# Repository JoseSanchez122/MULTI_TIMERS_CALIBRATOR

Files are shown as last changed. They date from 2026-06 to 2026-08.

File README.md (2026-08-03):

# MULTI_TIMERS_CALIBRATOR

Hardware_design



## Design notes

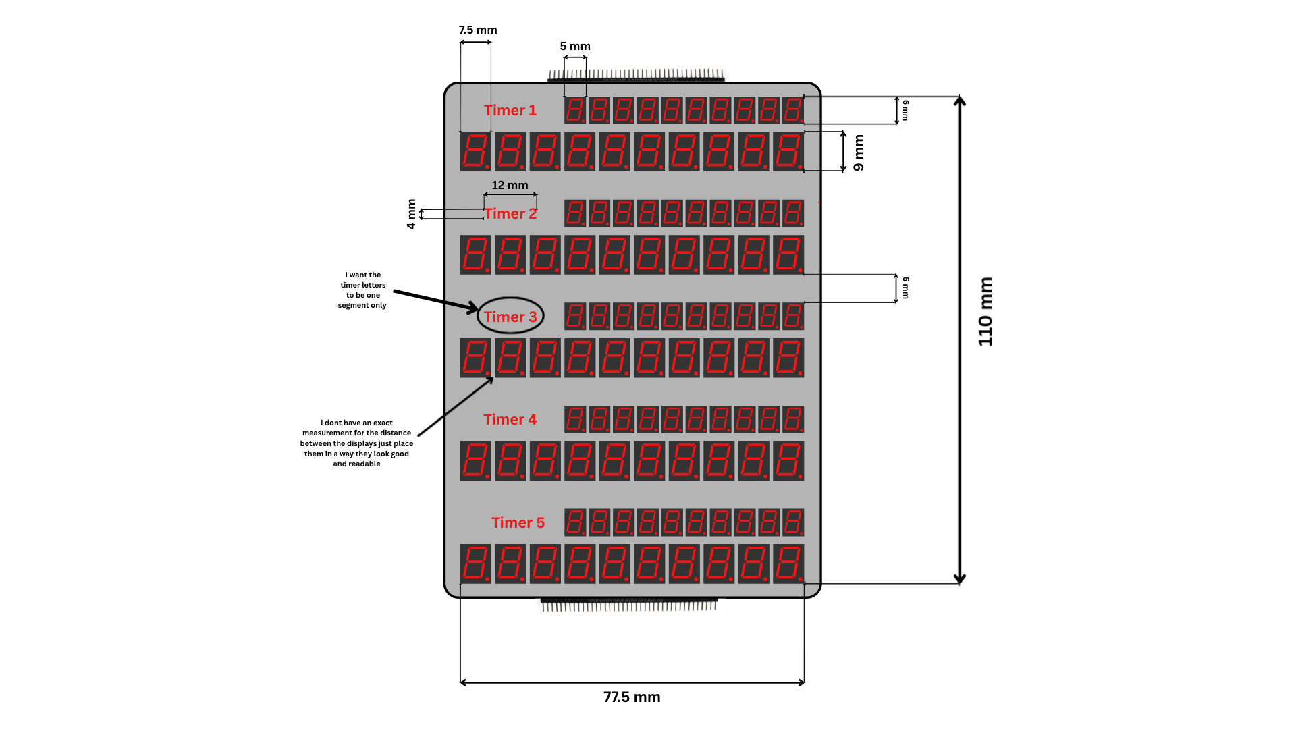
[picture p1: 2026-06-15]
Hardware_design/datasheets/Displays_datasheets/display.png

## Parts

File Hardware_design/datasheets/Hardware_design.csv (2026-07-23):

Id | Designator | Footprint | Quantity | Designation | Supplier and ref
1 | C1, C2, C3, C7 | 0805_SMD_CERAMIC_CAP_T491B106K016AT | 4 | 0.1uF
2 | C4, C8, C12, C13, C23, C24, C35, C36 | 0805_SMD_TANT_CAP_T491B106K016AT | 8 | 10uF
3 | C5, C6 | 0805_SMD_CERAMIC_CAP_T491B106K016AT | 2 | 15 pF
4 | C9, C10, C14, C15, C16, C17, C18, C19, C20, C21, C22, C25, C26, C27, C28, C29, C30, C31, C32, C33, C37 | 0805_SMD_CERAMIC_CAP_T491B106K016AT | 21 | 0.1 uF
5 | C11 | 0805_SMD_CERAMIC_CAP_T491B106K016AT | 1 | 1 uF
6 | D1 | Schottky_diode_BAT54S | 1 | BAT54S
7 | D2 | GREEN_LED_LTST-C170KGKT | 1 | LTST-C170KGKT
8 | D3, D4, D5, D6, D7, D8, D9, D10 | DIO_Schottky _MBR0530T3G | 8 | D_Schottky
9 | DS1, DS2, DS3, DS4, DS5, DS6, DS7, DS8, DS9, DS10, DS11, DS12, DS13, DS14, DS15, DS16, DS17, DS18, DS19, DS20, DS21, DS22, DS23, DS24, DS25, DS26, DS27, DS28, DS29, DS30, DS31, DS32, DS33, DS34, DS35, DS36, DS45, DS46, DS47, DS48, DS49, DS50, DS51, DS52, DS53, DS54, DS55, DS56, DS57, DS58, DS59, DS60, DS61, DS62, DS63, DS64, DS65, DS66, DS67, DS68, DS69, DS70, DS71, DS72, DS73, DS74, DS75, DS76 | SMD_DISPLAY_ACSC03-41EWA-F01 | 68 | ACSC03-41EWA-F01
10 | E1 | VNC_CONECTOR_1-1337445-0 | 1 | 1-1337445-0
11 | IC1 | ESP32S3WROOM1N16 | 1 | ESP32-S3-WROOM-1-N16
12 | J1 | PROG_CONECTOR_SAMTEC_FTSH-103-01-F-D | 1 | FTSH-103-01-F-D
13 | J2 | 4_pin_FTR-104-01-L-S | 1 | Conn_01x04_Pin
14 | J3 | POWER_CONE_54-00131 | 1 | 54-00131
15 | LS1 | BUZZER_CMI-9605IC-0580T | 1 | CMI-9605IC-0580T
16 | Q1 | TRANSISTOR_MMBT2222A | 1 | MMBT2222A
17 | R1, R2 | 0805_RES_RESC2012X60N | 2 | 10K
18 | R3, R4, R5, R6, R7, R8, R10, R11, R22, R23, R24, R25, R26, R27, R33, R34, R35, R36 | 0805_RES_RESC2012X60N | 18 | 10k
19 | R9 | 0805_RES_RESC2012X60N | 1 | 68
20 | R12, R13, R14, R15, R16, R17, R18, R19, R20 | 0805_RES_RESC2012X60N | 9 | 3v=24.5k, 1.8v=29.8k
21 | R21 | 0805_RES_RESC2012X60N | 1 | 1k
22 | R28, R29, R30, R31, R32, R38, R39, R40, R41 | 0805_RES_RESC2012X60N | 9 | 220
23 | SW1, SW2 | BUTTON_TL3301FF160QG | 2 | TL3301FF160QG
24 | SW3, SW4, SW5, SW6, SW7, SW8, SW9, SW10, SW11 | PUSH_BUTTON_ADTS24NV | 9 | ADTS24NV
25 | TP1, TP2, TP3, TP4, TP5, TP6, TP7, TP8, TP15 | TestPoint_Pad_1.0x1.0mm | 9 | TestPoint
26 | U1 | LS7366R-S | 1 | SOIC127P600X175-14N
27 | U2 | LEVEL_SHIFTER_TXB0104DR | 1 | TXB0104DR
28 | U3 | V_REGU_LP3875EMP-3.3 | 1 | LP3875EMP-3.3
29 | U4, U5, U6, U7, U8, U9, U10, U11, U12 | Disp_Controler_MAX7221CWG_ | 9 | MAX7221CWG_
30 | U15, U16 | Schimitt_Trigger_74HC14D_653 | 2 | 74HC14D_653

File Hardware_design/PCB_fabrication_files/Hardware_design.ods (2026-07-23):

Footprint | Quantity | Designation | ON STOCK
CC0805KRX7R9BB104 | 25 | 0.1uF | ✓ | https://www.digikey.com.mx/en/products/detail/yageo/CC0805KRX7R9BB104/302874
0805_SMD_TANT_CAP_T491B106K016AT | 8 | 10uF | ✓ | https://www.digikey.com.mx/es/products/detail/kemet/T491B106K016AT/818567
CC0805JPNPO9BN150 | 2 | 15 pF | ✓ | https://www.digikey.com.mx/en/products/detail/yageo/CC0805JPNPO9BN150/11491074
C0603C105K4RACTU | 1 | 1 uF | ✓ | 399-C0603C105K4RACTUCT-ND (https://www.digikey.com.mx/es/products/detail/kemet/C0603C105K4RACTU/2199788)
Schottky_diode_BAT54S | 1 | BAT54S | ✓ | https://www.digikey.com.mx/en/products/detail/diotec-semiconductor/BAT54S/13164121
GREEN_LED_LTST-C170KGKT | 1 | LTST-C170KGKT | ✓ | https://www.digikey.com.mx/en/products/detail/liteon/LTST-C170KGKT/386777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
DIO_Schottky _ 1N5819HW-FDICT-ND (https://www.digikey.com.mx/es/products/detail/diodes-incorporated/1N5819HW-7-F/814970) | 8 | D_Schottky | ✓ | https://www.digikey.com.mx/es/products/detail/diodes-incorporated/1N5819HW-7-F/814970
SMD_DISPLAY_ACSC03-41EWA-F01 | 68 | ACSC03-41EWA-F01 | NA
VNC_CONECTOR_1-1337445-0 | 1 | 1-1337445-0 | ✓ | https://www.digikey.com.mx/en/products/detail/te-connectivity-amp-connectors/1-1337445-0/1889630
ESP32S3WROOM1N16 | 1 | ESP32-S3-WROOM-1-N16 | ✓ | https://www.digikey.com.mx/es/products/detail/espressif-systems/ESP32-S3-WROOM-1-N16R8/16162642
FTSH-103-01-L-D | 1 | FTSH-103-01-L-D | ✓ | https://www.digikey.com.mx/en/products/detail/samtec-inc/FTSH-103-01-L-D/6678164
4_pin_FTR-104-01-L-S | 1 | Conn_01x04_Pin | ✓ | https://www.digikey.com.mx/en/products/detail/samtec-inc/FTR-104-01-L-S/7335482
POWER_CONE_54-00131 | 1 | 54-00131 | ✓ | https://www.digikey.com.mx/en/products/detail/tensility-international-corp/54-00131/9685440
AI-1027-TWT-5V-2-R | 1 | AI-1027-TWT-5V-2-R | ✓ | https://www.digikey.com.mx/en/products/detail/pui-audio-inc/AI-1027-TWT-5V-2-R/5011389
TRANSISTOR_MMBT2222A | 1 | MMBT2222A | check footprint | https://www.digikey.com.mx/en/products/detail/diotec-semiconductor/MMBT2222A/13163394
0805_RES_RC0805JR-0710KL | 20 | 10k | ✓ | https://www.digikey.com.mx/en/products/detail/yageo/RC0805JR-0710KL/728241
0805_RES_RC0805JR-0768RL | 1 | 68 | ✓ | https://www.digikey.com.mx/en/products/detail/yageo/RC0805JR-0768RL/728363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
0805_RES_RC0805FR-0724K3L | 9 | 3v=24.5k, actual = 24.3 k | ✓ | https://www.digikey.com.mx/en/products/detail/yageo/RC0805FR-0724K3L/727758
RC0805FR-0730K1L | 9 | 1.8v=29.8k | ✓ | https://www.digikey.com.mx/en/products/detail/yageo/RC0805FR-0730K1L/727845
0805_RES_RC0805FR-071KL | 1 | 1k | ✓ | https://www.digikey.com.mx/en/products/detail/yageo/RC0805FR-071KL/727444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
0805_RES_RC0805FR-07220RL | 9 | 220 | ✓ | https://www.digikey.com.mx/en/products/detail/yageo/RC0805FR-07220RL/727741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
BUTTON_TL3301FF160QG | 2 | TL3301FF160QG | ✓ | https://www.digikey.com.mx/en/products/detail/e-switch/TL3301FF160QG/1144800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
PUSH_BUTTON_ADTS24NV | 9 | ADTS24NV | ✓ | https://www.digikey.com.mx/en/products/detail/apem-inc/ADTS24NV/1798074?s=N4IgTCBcDaIIIBEAqBlMAWAcgNRAXQF8g
TestPoint_Pad_1.0x1.0mm | 9 | TestPoint | NA
LS7366R-S | 1 | SOIC127P600X175-14N | ✓ | https://www.digikey.com.mx/en/products/detail/lsi-csi/LS7366R-S/12760864
LEVEL_SHIFTER_TXB0104DR | 1 | TXB0104DR | ✓ | https://www.digikey.com.mx/en/products/detail/texas-instruments/TXB0104DR/1629101
V_REGU_LP3875EMP-3.3 | 1 | LP3875EMP-3.3 | ✓ | https://www.digikey.com.mx/en/products/detail/texas-instruments/LP3875EMP-3-3-NOPB/723535
Disp_Controler_MAX7221CWG_ | 9 | MAX7221CWG_ | NA
Schimitt_Trigger_74HC14D_653 | 2 | 74HC14D_653 | ✓ | https://www.digikey.com.mx/en/products/detail/nexperia-usa-inc/74HC14D-653/763005

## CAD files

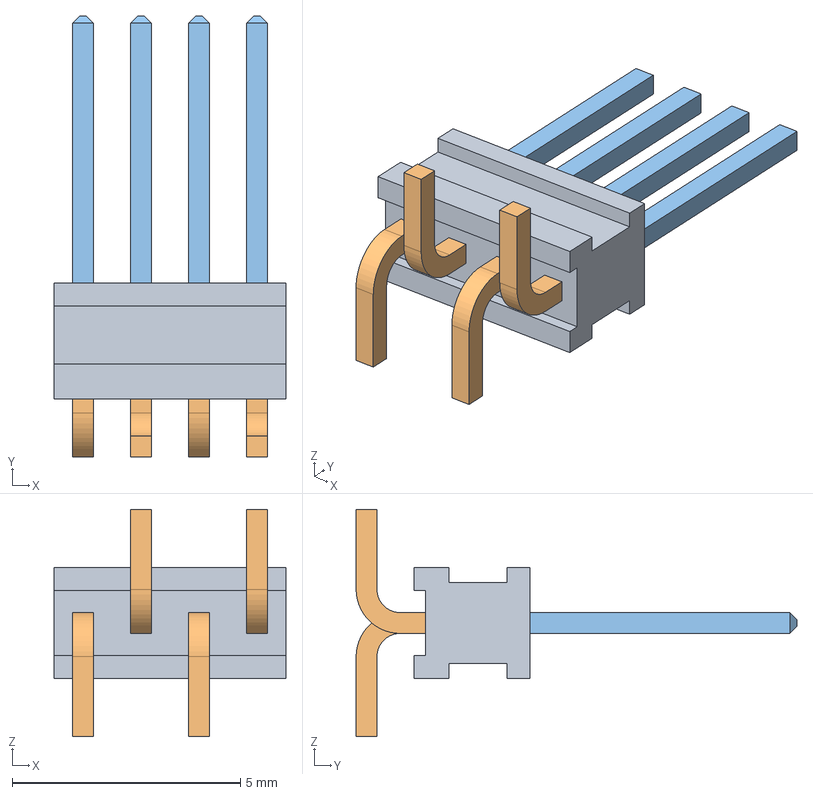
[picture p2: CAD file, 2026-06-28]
Hardware_design/parts/3D/FTR-104-01-L-S.stp
5.08 x 9.65 x 4.98 mm
FTR-104-01-L-S_body
FTR-104-01-L-S_pins
FTR-104-01-L-S2PNS

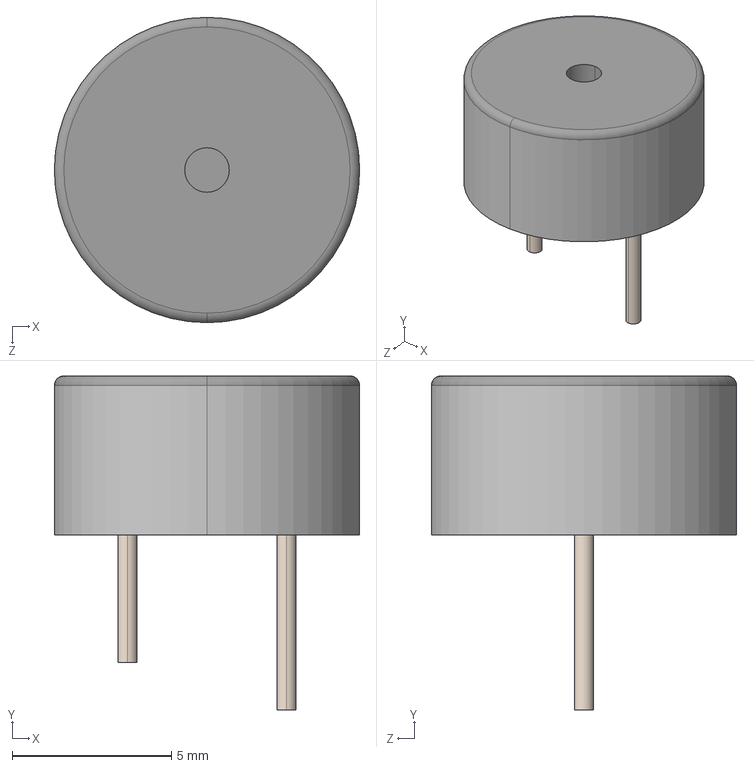
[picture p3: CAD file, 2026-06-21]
Hardware_design/parts/3D/BUZZER_CMI-9605IC-0580T.step
9.60 x 10.5 x 9.60 mm

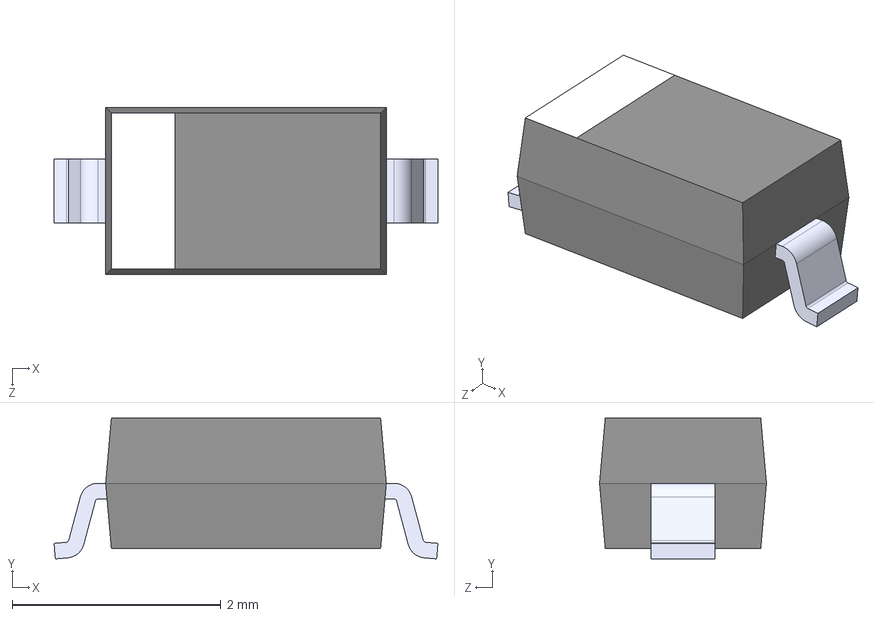
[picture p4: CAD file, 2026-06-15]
Hardware_design/parts/3D/DIO_Schottky _MBR0530T3G.step
3.68 x 1.35 x 1.60 mm

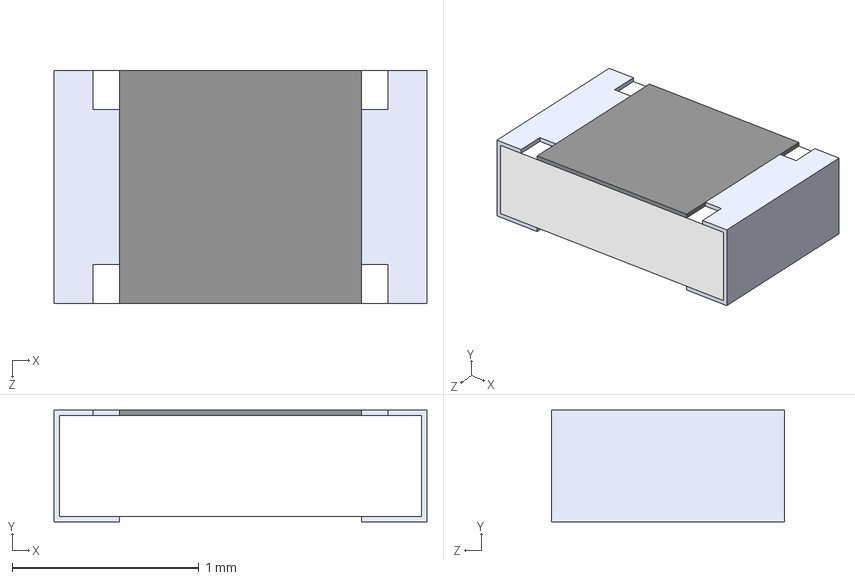
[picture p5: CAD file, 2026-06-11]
Hardware_design/parts/3D/0805_RES_RESC2012X60N.step
2.00 x 0.6 x 1.25 mm

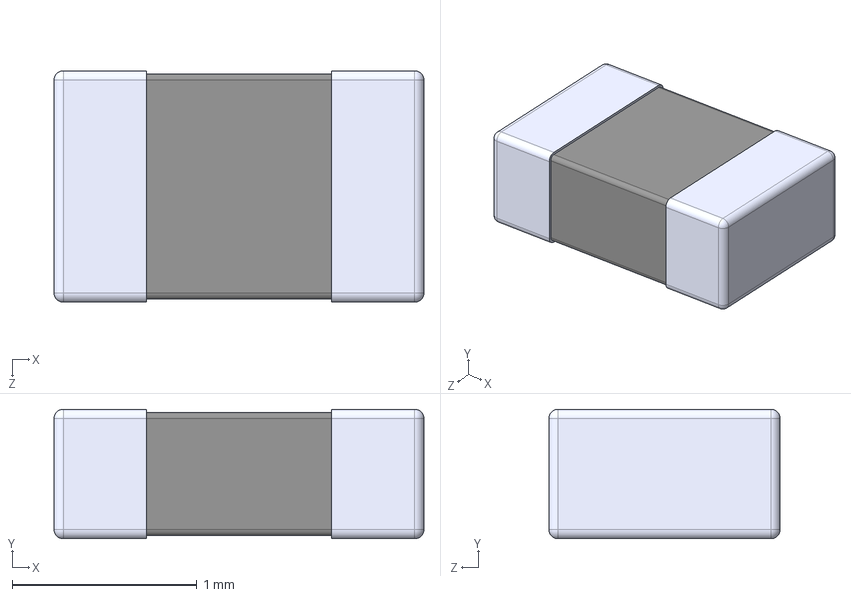
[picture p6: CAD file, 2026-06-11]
Hardware_design/parts/3D/0805_SMD_CERAMIC_CAP_T491B106K016AT.step
2.00 x 0.7 x 1.25 mm

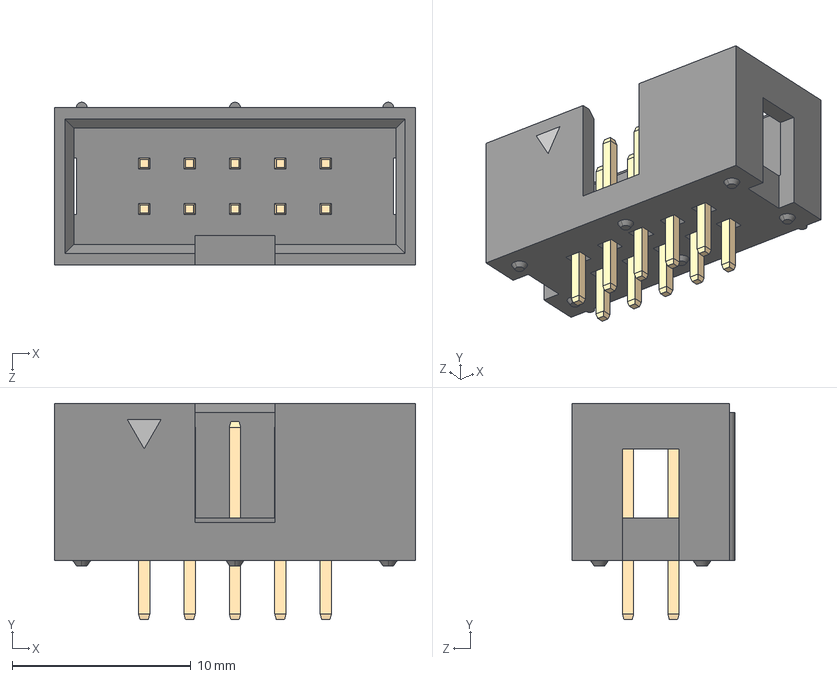
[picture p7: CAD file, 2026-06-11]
Hardware_design/parts/3D/JTAG_2.54_SBH11-PBPC-D05-ST-BK.step
20.2 x 12.1 x 9.09 mm

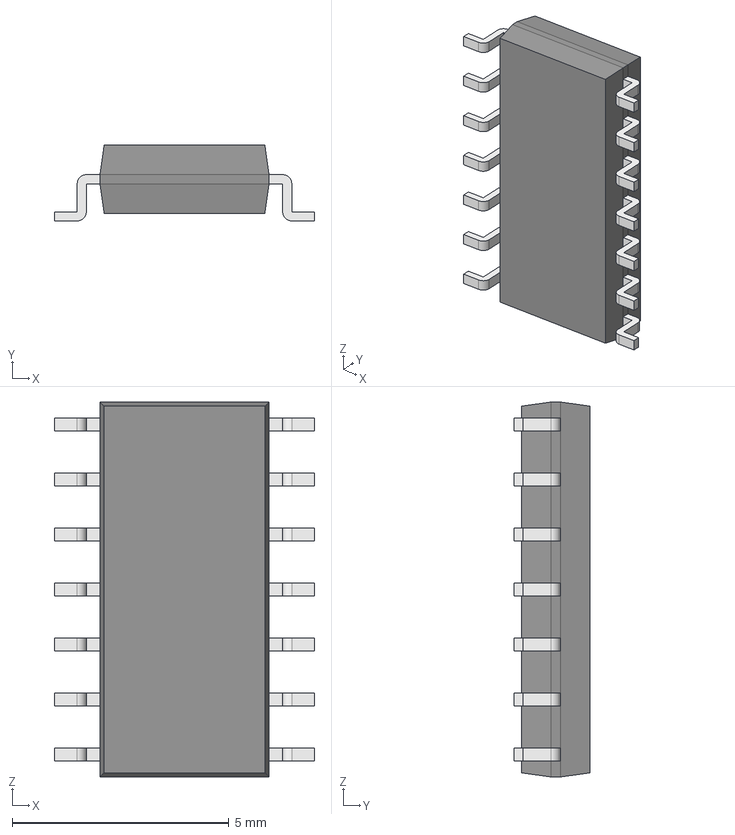
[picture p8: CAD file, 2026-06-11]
Hardware_design/parts/3D/LEVEL_SHIFTER_TXB0104DR.step
6.00 x 1.75 x 8.65 mm
Body001 (Mirror #1) x 7
XY-plane x 12
X-axis x 12

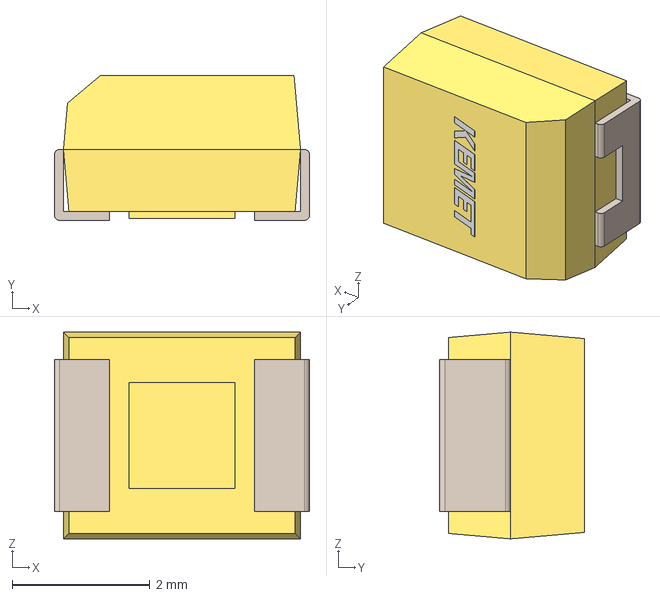
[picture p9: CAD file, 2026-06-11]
Hardware_design/parts/3D/0805_SMD_TANT_CAP_T491B106K016AT.stp
3.70 x 2.10 x 3.00 mm

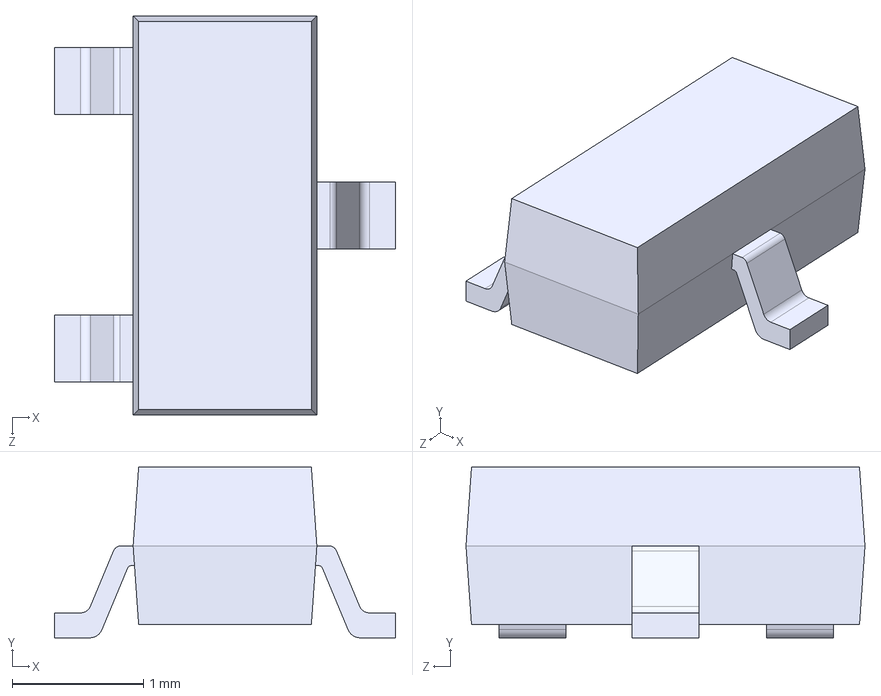
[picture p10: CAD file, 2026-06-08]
Hardware_design/parts/3D/TRANSISTOR_MMBT2222A.step
2.60 x 1.30 x 3.04 mm

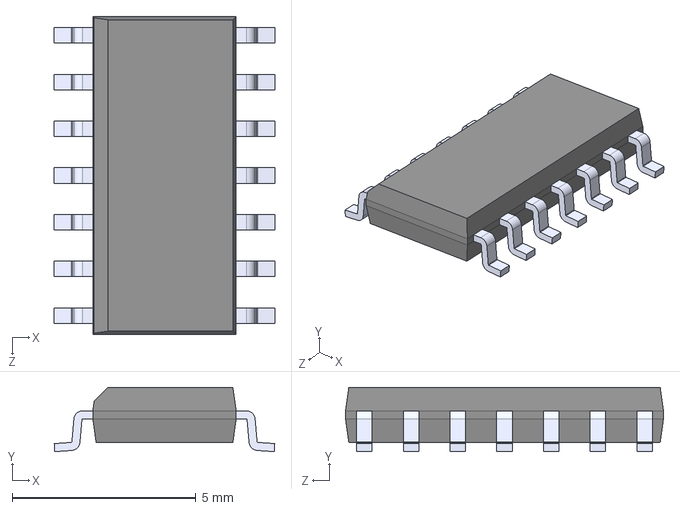
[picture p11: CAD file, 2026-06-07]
Hardware_design/parts/3D/Schimitt_Trigger_74HC14D_653.step
6.00 x 1.75 x 8.65 mm

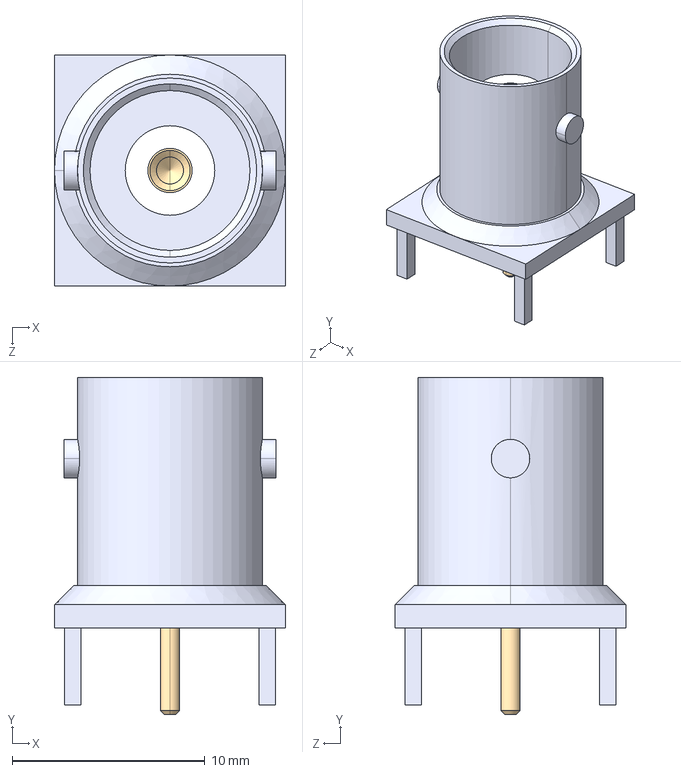
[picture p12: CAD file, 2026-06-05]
Hardware_design/parts/3D/VNC_CONECTOR_1-1337445-0.step
12.0 x 17.5 x 12.0 mm

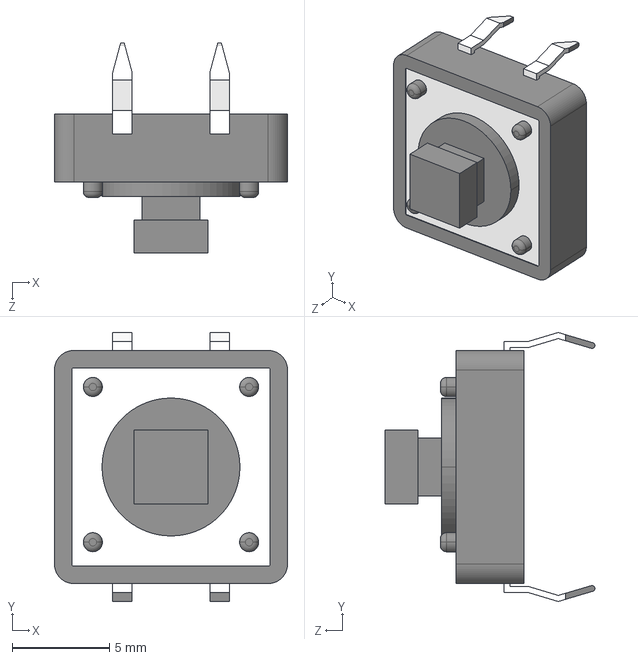
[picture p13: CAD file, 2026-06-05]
Hardware_design/parts/3D/PUSH_BUTTON_ADTS24NV.stp
12.0 x 13.8 x 10.8 mm

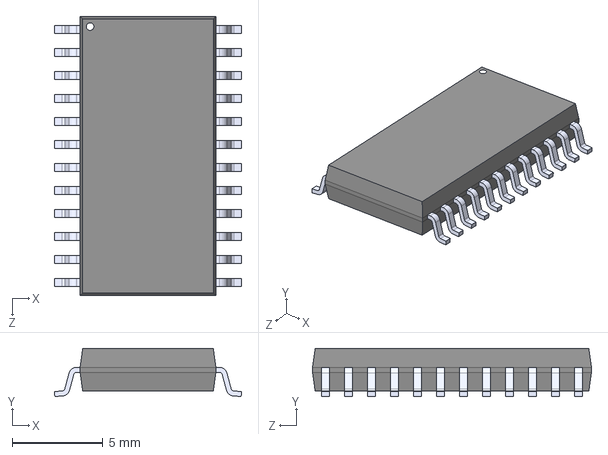
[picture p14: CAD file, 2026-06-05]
Hardware_design/parts/3D/Disp_Controler_MAX7221CWG_.step
10.3 x 2.65 x 15.4 mm

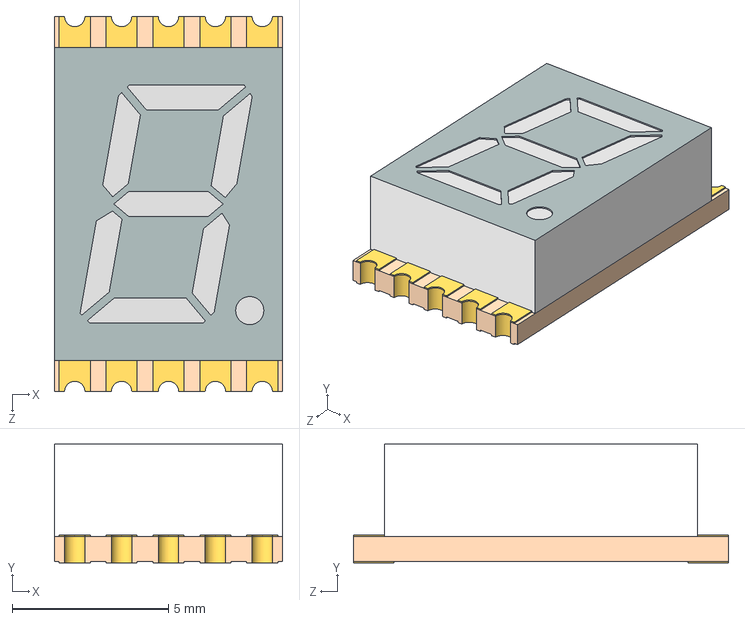
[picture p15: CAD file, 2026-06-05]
Hardware_design/parts/3D/SMD_DISPLAY_ACSC03-41EWA-F01.stp
7.30 x 3.80 x 12.0 mm

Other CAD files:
Hardware_design/parts/3D/BUTTON_TL3301FF160QG.step
Hardware_design/parts/3D/V_REGU_LP3875EMP-3.3.step
Hardware_design/parts/3D/LS7366R-S.step
Hardware_design/parts/3D/POWER_CONE_54-00131.step
Hardware_design/parts/3D/DEBOUNCE_CHIP_SN74LVC1G123DCTR.step
Hardware_design/parts/3D/ESP32-S3-WROOM-1-N16.stp
Hardware_design/parts/3D/GREEN_LED_LTST-C170KGKT.step
Hardware_design/parts/3D/PROG_CONECTOR_FTSH-103-01-F-D.step

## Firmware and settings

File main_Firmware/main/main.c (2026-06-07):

// set generator to 1.65 vpp
// set offset to 825 mv

//MY generator vpp = 2.6, offs = 1.2

#include <stdio.h>
#include "driver/gpio.h"
#include "freertos/FreeRTOS.h"
#include "esp_log.h"
#include "freertos/task.h"
#include "LS7366R.h"
#include "esp_task_wdt.h"

#define MISO 13
#define MOSI 11
#define SCLK 12
#define CS 10

#define LFLAG_PIN GPIO_NUM_5

ls7366r_handle_t LS7366R_1;
volatile BaseType_t  ISR_HAPPENED = false;

static void IRAM_ATTR isr_handler(void *arg)
{
    ISR_HAPPENED = true;
}

void app_main(void)
{
    ESP_ERROR_CHECK( esp_task_wdt_deinit() );

    ls7366r_spi_conf conf = {
        .miso_pin = MISO,
        .mosi_pin = MOSI,
        .sclk_pin = SCLK,
        .cs_pin = CS,
        .frequency = FREQ_10M
    };


    init_ls7366r_spi_com(&conf, &LS7366R_1);
    vTaskDelay(pdMS_TO_TICKS(100));

    LS7366R_WRITE_COMAND_AND_DATA(      // writing to MDR0 REG, non-quadrature mode, free runing mode, tansfer_CNTR_to_OTR
        (WRITE_TO | MDR0), 
        INDEX_LOAD_OTR, 
        Bits_8, 
        LS7366R_1);
        
    vTaskDelay(pdMS_TO_TICKS(10));
    
    LS7366R_WRITE_COMAND_AND_DATA(
        WRITE_TO | MDR1, 
        FLAG_ON_IDX | SET_OVERFLOW_FLAG, 
        Bits_8, 
        LS7366R_1); 

    vTaskDelay(pdMS_TO_TICKS(10));

    LS7366R_WRITE_COMAND(CLEAR | CNTR, LS7366R_1);  
    vTaskDelay(pdMS_TO_TICKS(10));

    gpio_config_t io_conf = {
        .pin_bit_mask = (1ULL << LFLAG_PIN),
        .mode = GPIO_MODE_INPUT,
        .pull_up_en = GPIO_PULLUP_DISABLE,
        .pull_down_en = GPIO_PULLDOWN_DISABLE,
        .intr_type = GPIO_INTR_NEGEDGE,  
    };
    gpio_config(&io_conf);
    
    // Instalar el servicio de interrupciones
    gpio_install_isr_service(ESP_INTR_FLAG_IRAM);
    
    // Asignar el handler al pin
    gpio_isr_handler_add(LFLAG_PIN, isr_handler, NULL);

    uint32_t pulsos_acumulados = 0;
    
    while (1) {

        if (ISR_HAPPENED) {
            ISR_HAPPENED = false;
            pulsos_acumulados = LS7366R_READ(READ_FROM | OTR, Bits_32, LS7366R_1);
            printf("Pulsos acumulados: %lu\n", pulsos_acumulados);
            LS7366R_WRITE_COMAND(CLEAR | STR, LS7366R_1); 
        }
          
        //vTaskDelay(pdMS_TO_TICKS(500));
    }

}

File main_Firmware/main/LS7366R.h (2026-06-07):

#ifndef LS7366R_H
#define LS7366R_H

#include "driver/spi_master.h"

//Registers
#define MDR0 0x8
#define MDR1 0X10
#define DTR  0X18
#define CNTR 0X20 // real time counter register
#define OTR  0X28 // CNTR Back up register, for storing CNTR values without stoping CNTR to count.
#define STR  0X30 // status register, for cheking counter configurations and events that happend

//Instructions
#define CLEAR       0x00   // 00000000
#define READ_FROM   0x40   // 01000000
#define WRITE_TO    0x80   // 10000000
#define LOAD_TO     0xC0   // 11000000

//MDR1 Configurations
#define FLAG_ON_IDX         0x10 // flags activated when INDEX interruption ocurrs 
#define SET_OVERFLOW_FLAG   0x80 // FLAG on overflow

//MDR0 configurations
#define non_quadrature          0x00
#define free_runing             0x00
#define INDEX_LOAD_OTR          0x30



// Frequency for SPI comunication
#define FREQ_8M      (80 * 1000 * 1000 / 10)   ///< 8MHz
#define FREQ_9M      (80 * 1000 * 1000 / 9)    ///< 8.89MHz
#define FREQ_10M     (80 * 1000 * 1000 / 8)    ///< 10MHz
#define FREQ_11M     (80 * 1000 * 1000 / 7)    ///< 11.43MHz
#define FREQ_13M     (80 * 1000 * 1000 / 6)    ///< 13.33MHz
#define FREQ_16M     (80 * 1000 * 1000 / 5)    ///< 16MHz
#define FREQ_20M     (80 * 1000 * 1000 / 4)    ///< 20MHz
#define FREQ_26M     (80 * 1000 * 1000 / 3)    ///< 26.67MHz
#define FREQ_40M     (80 * 1000 * 1000 / 2)    ///< 40MHz
#define FREQ_80M     (80 * 1000 * 1000 / 1)    ///< 80MHz

//Bit comunication info size
#define Bits_8 8
#define Bits_16 16
#define Bits_32 32

typedef spi_device_handle_t ls7366r_handle_t;

// SPI pin configuration structure
typedef struct {
    uint8_t miso_pin;
    uint8_t mosi_pin;
    uint8_t sclk_pin;
    uint8_t cs_pin;
    int frequency;

} ls7366r_spi_conf;

esp_err_t init_ls7366r_spi_com(ls7366r_spi_conf *conf, ls7366r_handle_t *ls7366r_handle);
esp_err_t LS7366R_WRITE_COMAND(uint8_t command, ls7366r_handle_t ls7366r_handle);
esp_err_t LS7366R_WRITE_COMAND_AND_DATA(uint8_t command, uint32_t data, uint8_t bits_length, ls7366r_handle_t ls7366r_handle);
uint32_t LS7366R_READ(uint8_t command, uint8_t bits_length, ls7366r_handle_t ls7366r_handle);
    
#endif

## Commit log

2026-05-25 starting the spi comunication example
2026-05-25 starting spi driver configuration
2026-05-29 hardware design initiated
    [Hardware_design.kicad_pcb, Hardware_design.kicad_sch]
2026-05-30 starting hardware proyect
    looking for componets, symbols, footprints, etc
    [ESP32-S3-WROOM-1-N16.stp]
2026-05-31 starting to add the components
    some symbols and footprints have been added after carefull consideration, there are still more to add
    [BUTTON_TL3301FF160QG.step, DEBOUNCE_CHIP_SN74LVC1G123DCTR.step, ESP32-S3-WROOM-1-N16.stp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]
2026-06-05 component_search_finidhed
    starting to design schematics
    [Disp_Controler_MAX7221CWG_.step, Display_management.kicad_sch, Hardware_design.kicad_sch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]
2026-06-06 INDEX INTERRUPTION working
    the device has been configured for transfering the cntr reg count data to the otr reg so it stores data at a precise moment so when we want to read it later with the esp32se we get the count at that 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
    [Hardware_design.kicad_sch]
2026-06-06 ISR ATTEMPT
    FOR now isr is not working properly, message is being sent twice, but i'll work on it, don't worry
    [main.c]
2026-06-07 interrupt routine working
    the interrupt routine is already working but it is being activated in falling and rising edge, Even though the isr copnfiguration is set to be activaded on falling edge, the problem is that the activation signal that the isr pin needs to be a clean signal, because the button signal has too much noise and even with a low pass filter the signal is too slow, i tried using a signal generator and the interruption worked properly, only on falling edge, so we need a clean signal, the plan is to use a 74HC_HCT14 chip to clean the button signal
    [main.c]
2026-06-07 interrupt execution
    interrupt already working, comming from counter flag to esp32 interrupt pin, interruption is being handled properly by esp32 and working fine with the LFLAG interrption flag pin from the counter, it 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
    [Schimitt_Trigger_74HC14D_653.step]
2026-06-08 schematic progress
    saving schematic progress, butons added but a change is pending to use 10 buttons instead of 15
    [Buttons_circuits.kicad_sch, Hardware_design.kicad_sch, Schottky_diode_BAT54S.STEP]
2026-06-08 Buttons number modified
    now the buttons are 10, one is for starting and stoping the count and another one for reseting it
    [Buttons_circuits.kicad_sch, Display_management.kicad_sch, Hardware_design.kicad_sch]
2026-06-08 STARTING THE DISPLAY design
    acording to calculations we will need around 1.848 A when working with all the displays at the same time, including the MAX7221, the 1.848 A consumption is only for the display part.
    [Display_management.kicad_sch, Hardware_design.kicad_sch]
2026-06-09 display set up completed
    for the displays we will not need an aditional voltage regulator becuase we will use the direct conection from the 5V power supply of the circuit, it needs to be able to provide at least 3A, recomend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
    [Display_management.kicad_sch]
2026-06-11 starting footprint asignment
    [0805_SMD_CERAMIC_CAP_T491B106K016AT.step, 0805_SMD_TANT_CAP_T491B106K016AT.stp, Buttons_circuits.kicad_sch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]
2026-06-11 all footprints asigned
    [0805_RES_RESC2012X60N.step, Buttons_circuits.kicad_sch, Display_management.kicad_sch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]
2026-06-13 pcb layout started
    concecting first MAX7221 and its 8 displays
    [Hardware_design.kicad_pcb]
2026-06-13 10 uF display caps deleted
    10 uF display caps ocupy too much space, they were deleted
    [Display_management.kicad_sch, Hardware_design.kicad_pcb]
2026-06-14 component placement started
    index pin and gpio pins for 10 buttons problem, index pin should be activated whenever any of the 10 buttons is pressed but only the gpio pin of the button that was pressed should also be activaded
    [Hardware_design.kicad_pcb, Hardware_design.kicad_sch]
2026-06-15 Index problem solved and some progress made
    [Buttons_circuits.kicad_sch, DIO_Schottky _MBR0530T3G.step, Hardware_design.kicad_pcb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]
2026-06-21 big update
    coper zones already set, edgecuts set, all components placed, we are just missing the routing
    [BUZZER_CMI-9605IC-0580T.step, Buttons_circuits.kicad_sch, Display_management.kicad_sch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]
2026-06-21 a little advance
    [Buttons_circuits.kicad_sch, Hardware_design.kicad_pcb]
2026-06-28 almost finished
    just missing final conections and verification of constrains for fabrication
    [FTR-104-01-L-S.stp, Hardware_design.kicad_pcb, Hardware_design.kicad_sch]
2026-07-02 almost finished
    all conections made, need to fixed errors and warnings, minimum via size error for hole and diameter, also silkscreen text error.
    [Display_management.kicad_sch, Hardware_design.kicad_pcb]
2026-07-23 final design
    [Displays_PCB_Test.kicad_pcb, Displays_PCB_Test.kicad_sch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]

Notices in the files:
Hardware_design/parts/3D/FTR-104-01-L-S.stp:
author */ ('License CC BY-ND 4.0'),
